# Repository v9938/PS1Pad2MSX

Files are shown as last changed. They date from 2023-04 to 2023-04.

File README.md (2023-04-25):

# PlayStation 1/2 joypad to MSX Joystick Converter  

This is a PlayStation 1/2 joypad to MSX Joystick converter using Arduino.  
It requires installation of PlayStation 1/2 joypads library for Arduino IDE.

Instructions for wiring follows below.

## To PSX joypad  

|PSX Pin | PSX Signal | Arduino Pin | Arduino Signal |
| :- |  :- |  :- |  :- |
| 1 | DAT | D12 | MISO [need pullup by 1k owm registor to 5V] |
| 2 | CMD | D11 | MOSI |
| 3 | 9V (for motor, If you not necessary NC)| - | - |
| 4 | GND | GND | Power GND |
| 5 | 3.3V | 3.3V | Power 3.3V |
| 6 | Attention | D2 | Digital Pin |
| 7 | SCK | D13 | SCK |
| 8 | NC | - | - |
| 9 | ACK | - | - |

## To MSX Joystick  

|MSX DSUB Pin | MSX Joystick Signal | Arduino Pin | Arduino Signal |
| :- |  :- |  :- |  :- |
| 1 | UP | D4 | Digital Pin |
| 2 | DOWN | D5 | Digital Pin |
| 3 | LEFT | D6 | Digital Pin |
| 4 | RIGHT | D7 | Digital Pin |
| 5 | +5V | +5V | Power +5V |
| 6 | TRIG A | D8 | Digital Pin |
| 7 | TRIG B | D9 | Digital Pin |
| 8 | COM | - | - |
| 9 | GND | GND | Power GND |

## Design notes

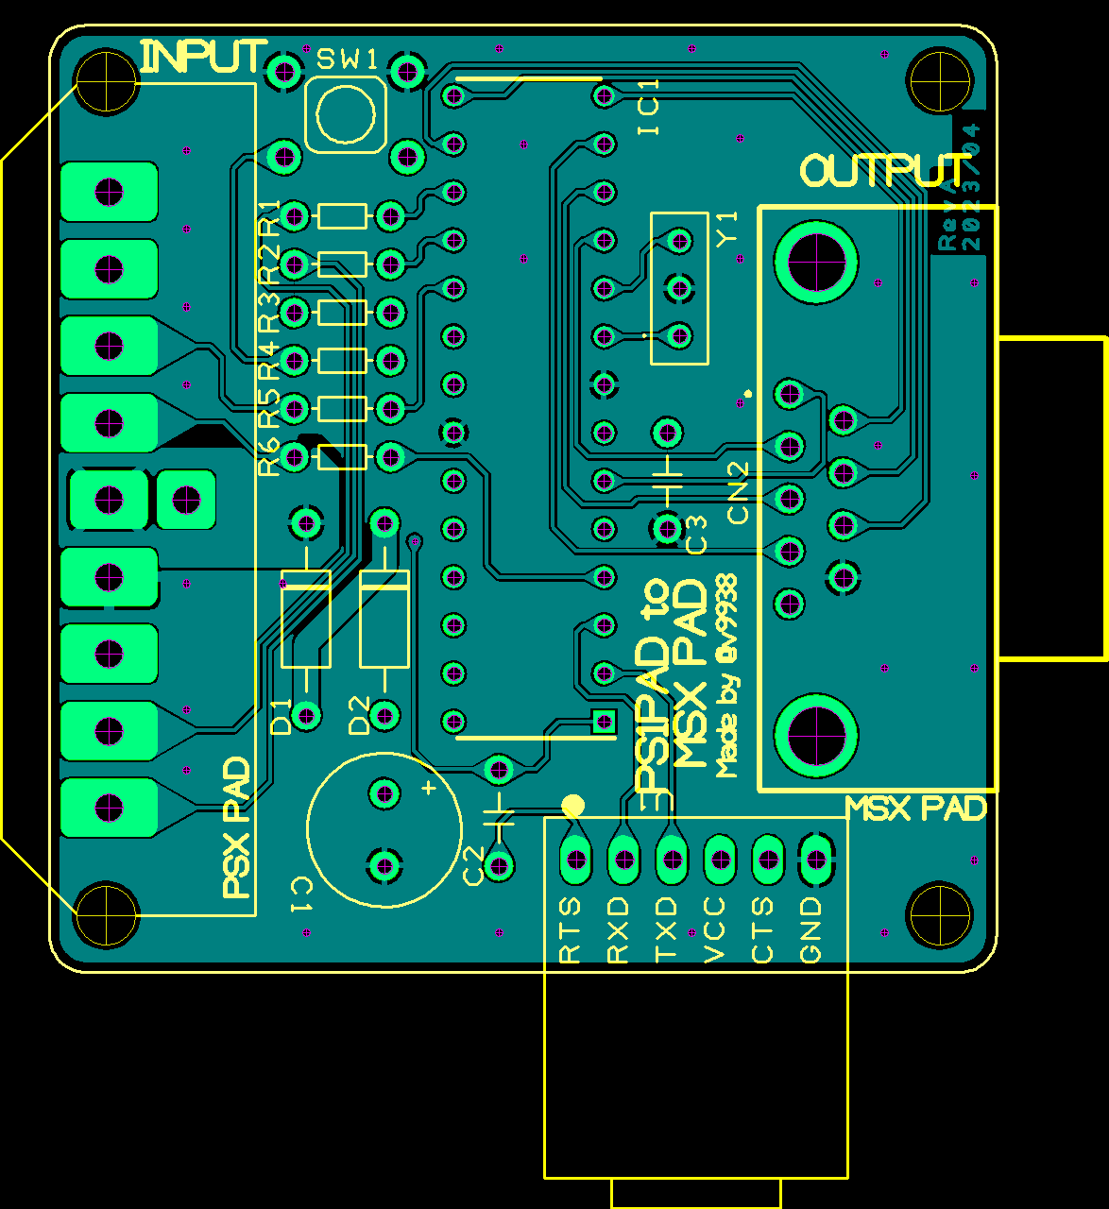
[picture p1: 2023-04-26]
PCB/PS1PAD2MSX(TOP).png

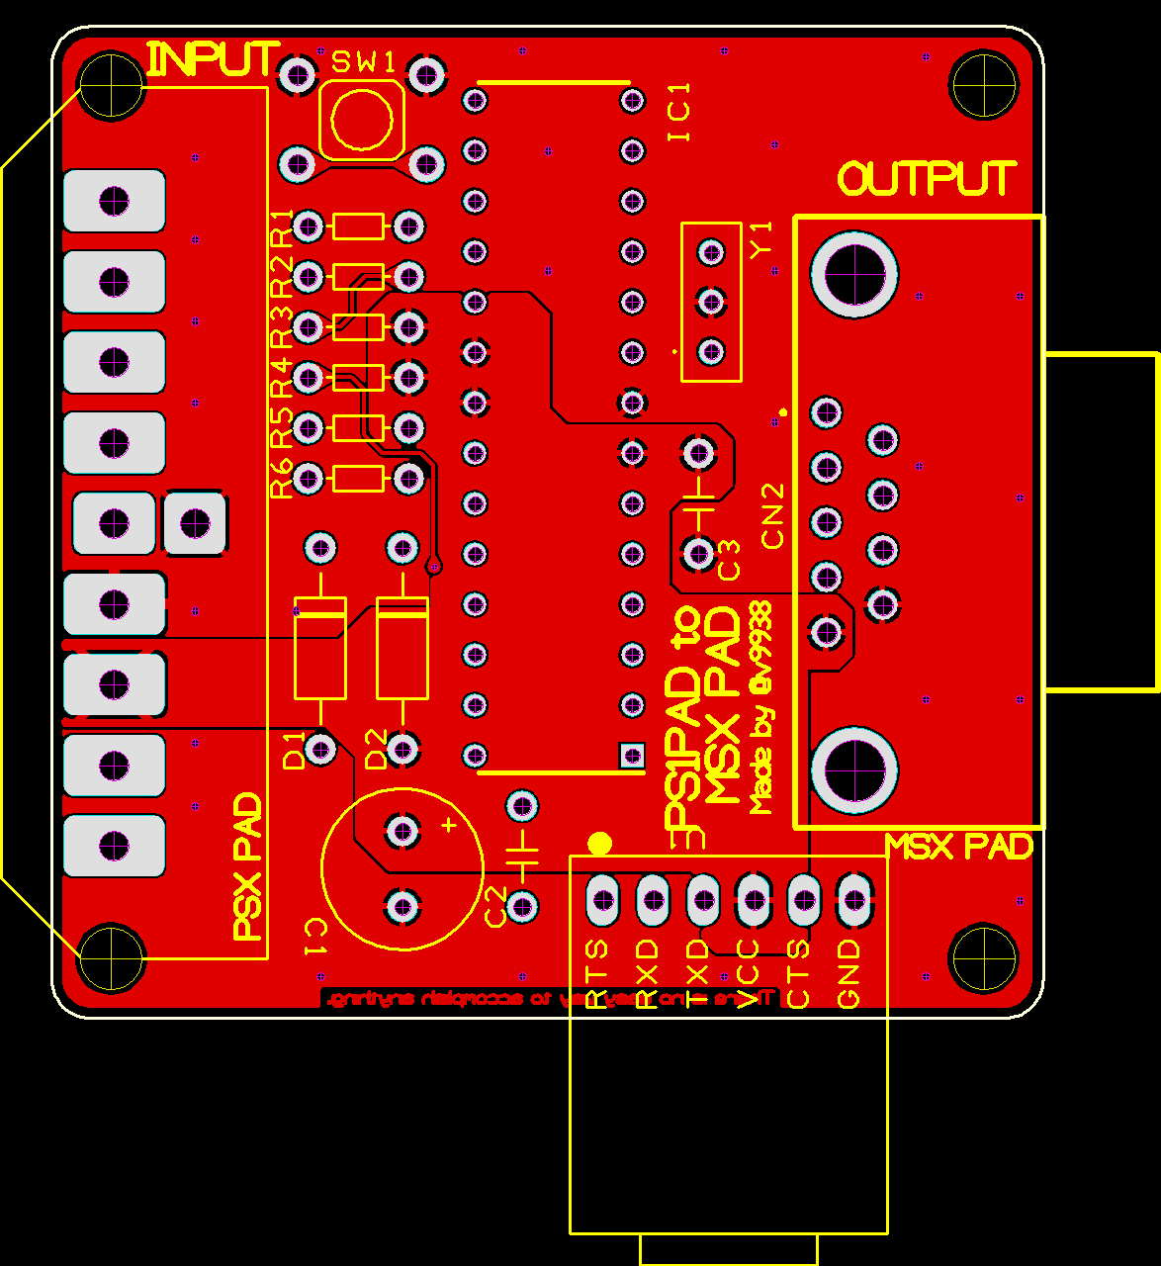
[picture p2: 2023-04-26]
PCB/PS1PAD2MSX(BOTTOM).png

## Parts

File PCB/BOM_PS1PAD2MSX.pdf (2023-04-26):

### Bill Of Materials

ICs

Capacitors

Diodes

Resistors

Component | Names | Value | Part Number | Quantity | Cost
USB Serial Unit | U1 | | | 1 | 0.00
ATMEGA328P-PU | IC1 | | | 1 | 0.00
Sub-total: | | | | 2 | 0.00
Component | Names | Value | Part Number | Quantity | Cost
C5.08 | C2, C3 | 0.1uF | | 2 | 0.00
CP | C1 | 100uF | | 1 | 0.00
Sub-total: | | | | 3 | 0.00
Component | Names | Value | Part Number | Quantity | Cost
1N4107 | D1, D2 | | | 2 | 0.00
Sub-total: | | | | 2 | 0.00
Component | Names | Value | Part Number | Quantity | Cost
R 1/8W | R1, R4, R5, R6 | 1K | | 4 | 0.00

Others

Grand Totals

R 1/8W | R2 | 470 | 1 | 0.00
R 1/8W | R3 | 2.2K | 1 | 0.00
Sub-total: | | | 6 | 0.00
Component | Names | Value | Part Number | Quantity | Cost
A-DF_09_A_KG-T2S | CN2 | | | 1 | 0.00
CSTLS8M00G53-A0 | Y1 | | | 1 | 0.00
PSX Controler connector | CN1 | | | 1 | 0.00
SW_FSM2JH | SW1 | | | 1 | 0.00
Sub-total: | | | | 4 | 0.00
Quantity | Cost
17 0.00

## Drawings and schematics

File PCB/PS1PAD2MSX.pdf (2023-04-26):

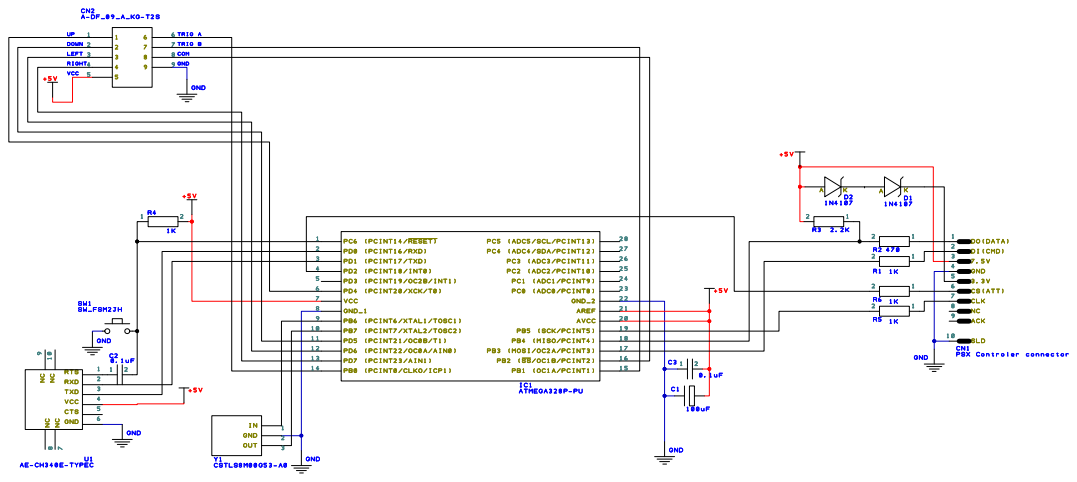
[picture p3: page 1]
PS1PAD2MSX; Rev A

PS1PAD to MSX Joystick Converter

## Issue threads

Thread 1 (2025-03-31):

Can't found PSXpad.h file

hpx1984, 2025-03-31:
Hi Sir

i got the error is "not found PSXpad.h file" when i upload FW to the board
but actually i had put this file into the same folder

hpx1984, 2025-04-03:
thank you Sir
now i can upload the FW(PS1Pad2MSX.ino) to the board and also completed the HW
but test PS2 GamePad is no function on MSX

already check the HW many times and i can sure no soldering issue

hpx1984, 2025-04-03:
thank you Sir
now i can upload the FW(PS1Pad2MSX.ino) to the board and also completed the HW
but test PS2 GamePad is no function on MSX

already check the HW many times and i can sure no soldering issue

hpx1984, 2025-04-03:
Found the problem,
i miss one component ,now it can working

Closed 2025-04-03.

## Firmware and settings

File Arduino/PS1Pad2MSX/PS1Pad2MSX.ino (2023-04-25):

////////////////////////////////////////////////////////////////////////
//
// PSX Controller to MSX Joystick Sample
// Copyright 2023 @V9938
//	
//	23/01/20 V0.1		1st version
//
// This program requires "PlayStation 1/2 joypads library for Arduino IDE".
// https://domisan.sakura.ne.jp/article/arduino_psxpad/arduino_psxpad.html
//
////////////////////////////////////////////////////////////////////////

#include <PSXPad.h>

byte lbAttPinNos[] = {2};
PSXPad_KeyState_t tKeyState;

void setup() {
//  Serial.begin(115200);
  PSXPads.begin(1, lbAttPinNos);
  pinMode(4, OUTPUT);					// Digital4 => MSX JOYSTICK PIN1 [UP]
  pinMode(5, OUTPUT);					// Digital5 => MSX JOYSTICK PIN2 [DOWN]
  pinMode(6, OUTPUT);					// Digital6 => MSX JOYSTICK PIN3 [LEFT]
  pinMode(7, OUTPUT);					// Digital7 => MSX JOYSTICK PIN4 [RIGHT]
  pinMode(8, OUTPUT);					// Digital8 => MSX JOYSTICK PIN6 [TRIG A]
  pinMode(9, OUTPUT);					// Digital9 => MSX JOYSTICK PIN7 [TRIG B]
  
  digitalWrite(4, HIGH);				// Default value [UP]
  digitalWrite(5, HIGH);				// Default value [DOWN]
  digitalWrite(6, HIGH);				// Default value [LEFT]
  digitalWrite(7, HIGH);				// Default value [RIGHT]
  digitalWrite(8, HIGH);				// Default value [TRIG A]
  digitalWrite(9, HIGH);				// Default value [TRIG B]
  
}

void loop() {
  PSXPads.pool();
  PSXPads.lpcPads[0]->getKeyState(&tKeyState);
//  if(tKeyState.bSel) Serial.print("Sel ");
//  if(tKeyState.bL3) Serial.print("L3 ");
//  if(tKeyState.bR3) Serial.print("R3 ");
//  if(tKeyState.bStt) Serial.print("Stt ");
//  if(tKeyState.bU) Serial.print("U ");
//  if(tKeyState.bR) Serial.print("R ");
//  if(tKeyState.bD) Serial.print("D ");
//  if(tKeyState.bL) Serial.print("L ");
//  if(tKeyState.bL2) Serial.print("L2 ");
//  if(tKeyState.bR2) Serial.print("R2 ");
//  if(tKeyState.bL1) Serial.print("L1 ");
//  if(tKeyState.bR1) Serial.print("R1 ");
//  if(tKeyState.bTri) Serial.print("Tri ");
//  if(tKeyState.bCir) Serial.print("Cir ");
//  if(tKeyState.bCrs) Serial.print("Crs ");
//  if(tKeyState.bSqr) Serial.print("Sqr ");
//  Serial.print("\r\n");


// PSX data to MSX Controller
  if(tKeyState.bU)		digitalWrite(4, LOW); else digitalWrite(4, HIGH);	// [UP]
  if(tKeyState.bD)		digitalWrite(5, LOW); else digitalWrite(5, HIGH);	// [DOWN]
  if(tKeyState.bL)		digitalWrite(6, LOW); else digitalWrite(6, HIGH);	// [LEFT]
  if(tKeyState.bR)		digitalWrite(7, LOW); else digitalWrite(7, HIGH);	// [RIGHT]

  if(tKeyState.bCrs) 	digitalWrite(8, LOW); else digitalWrite(8, HIGH);	// [TRIG A]
  if(tKeyState.bSqr) 	digitalWrite(9, LOW); else digitalWrite(9, HIGH);	// [TRIG B]

}
